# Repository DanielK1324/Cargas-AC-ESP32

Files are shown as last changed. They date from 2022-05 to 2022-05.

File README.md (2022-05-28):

# Cargas-AC-ESP32

Este dispositivo fue diseñado como proyecto final de curso aplicando IOT (Internet de las Cosas)

El dispositivo contiene:

- ESP32
- NeoPixeles
- Buzzer
- SHT30
- Control de cargas AC

# ¿Cómo funciona?

# ¿Qué podemos hacer?

# Descripción de pines 

### Pantalla OLED SSD 1306, Temperatura y Humedad – Comunicación I2C
Referencia --- | SSD 1306 | --- | SHT30 |
ESP32            | SCL IO22 | --- | SCL IO22 |
---------------- | -------- |---- | -------- |
| SSD 1306| --- | SHT30 | 
| SCL IO22 | -- | SCL IO22 |
| SDA IO23 | -- | SDA IO23 |

### Control Cargas AC 
Referencia --- | CARGA 1 | --- | CARGA 2 | --- | CARGA 3 |
ESP32          |  IO25   | --- |  IO26   | --- |  IO27   | 

### LED Neopixel - Comunicación SPI
Referencia --- | WS2812B | 
ESP32            |   SD3   |
5V | VCC 

GND | GND

### Control Cargas AC 
Referencia --- | SCT 013 | --- | Voltaje AC |
ESP32          |  IO15   | --- |     IO2    |
               | ADC2_2  | --- |   ADC2_3   |
# Licencia

Hardware License: CERN OHL v1.0 para más información visitar el siguiente [Link][CERN_v1].

[CERN_v1]: https://ohwr.org/project/cernohl/wikis/Documents/CERN-OHL-version-1.2

Software License: GPL v3

Documentation License: CC BY 4.0 International

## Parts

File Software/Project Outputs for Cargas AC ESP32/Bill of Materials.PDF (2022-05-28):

Comment | Description | Designator | Footprint | LibRef | Quantity
Boton | Micro Push TH | B1, B2 | Push Boton 2P C | Push Boton 2 Pin TH | 2
Buzzer | Active Sound | B3 | Buzzer | Buzzer | 1
100nF | Capacitor cerámico 1206 SMD | C1, C2, C3, C4, C5, C6, C9 | Capacitor 1206 | Capacitor 1206 | 7
10uF | | C7, C8 | 100uF | CAP-ELEC-100uF | 2
1N4004 | Diodo Rectificador | D1, D2, D3 | 1N4007 SMD | 1N4007 SMD | 3
T-Block | Terminal de Bloque 2P 5.08mm | H1, H2, H3, H4 | TBLOCK-2ORANGE | T-Block 5.08mm 2P | 4
ESP32-WRover | ESP32-WRover 39Pins | IC1 | ESP32-WROVER-B | ESP32-WRover | 1
SHT3X | SHT3X | IC2 | DFN-8_DD | SHT3X | 1
PJ-3136 | PJ-3136 Jack De Audio Hembra | J1 | PJ-3136-X | JACK HEMBRA 3.5MM | 1
LED 1206 | LED SMD 1206 | L1 | LED 1206 G | LED 1206 | 1
LED 1206 | LED SMD 1206 | L2 | LED 1206 R | LED 1206 | 1
SSD 1306 | Pantalla OLED 124x64 | L3 | OLEDSSD1306 | SSD 1306 | 1
NEOPIXEL-WS2812B | LED NEOPIXEL WS2812B | L4 | WS2812B | NEOPIXEL-WS2812B | 1
10K | Resistencia SMD 1206 | R1, R2, R3, R4, R5, R6, R9, R10, R16 | Resistencia 1206 | Resistencia SMD 1206 | 9
5.1K | Resistencia SMD 1206 | R7, R8 | Resistencia 1206 | Resistencia SMD 1206 | 2
1K | Resistencia SMD 1206 | R11 | Resistencia 1206 | Resistencia SMD 1206 | 1
100K | Resistencia SMD 1206 | R12 | Resistencia 1206 | Resistencia SMD 1206 | 1
470K | Resistencia SMD 1206 | R13, R14, R19, R20 | Resistencia 1206 | Resistencia SMD 1206 | 4
470 | Resistencia SMD 1206 | R15, R18, R21, R22, R23, R24 | Resistencia 1206 | Resistencia SMD 1206 | 6
22 | Resistencia SMD 1206 | R17 | Resistencia 1206 | Resistencia SMD 1206 | 1
Relevador | Relevador Mini | RL1, RL2, RL3 | Relevador Mini 20A | Relevador S 5V 20A | 3
MMTB2N2222 | | T1, T2 | SOT23_M | MMBT2N2222A | 2
2N3904 | | T3 | NewTO-92A | 2N3904 | 1
2N3904 | | T4, T5, T6 | SOT23_M | MMBT2N3904 | 3
CH340B | USB-Serial Converter | U1 | SOIC 16 | CH340B | 1
AMS1117-3.3V | Regulador Lineal de Voltaje | U2 | SOT 223 | AMS1117 | 1
PC817 | Optoacoplador NPN | U3, U4, U5 | PC817 | PC817 | 3
USB TYPEC C 16PINS | USB Type C 16 Pins | USB-C1 | USB-TYPE_C-16 | USB TYPEC C 16PINS | 1

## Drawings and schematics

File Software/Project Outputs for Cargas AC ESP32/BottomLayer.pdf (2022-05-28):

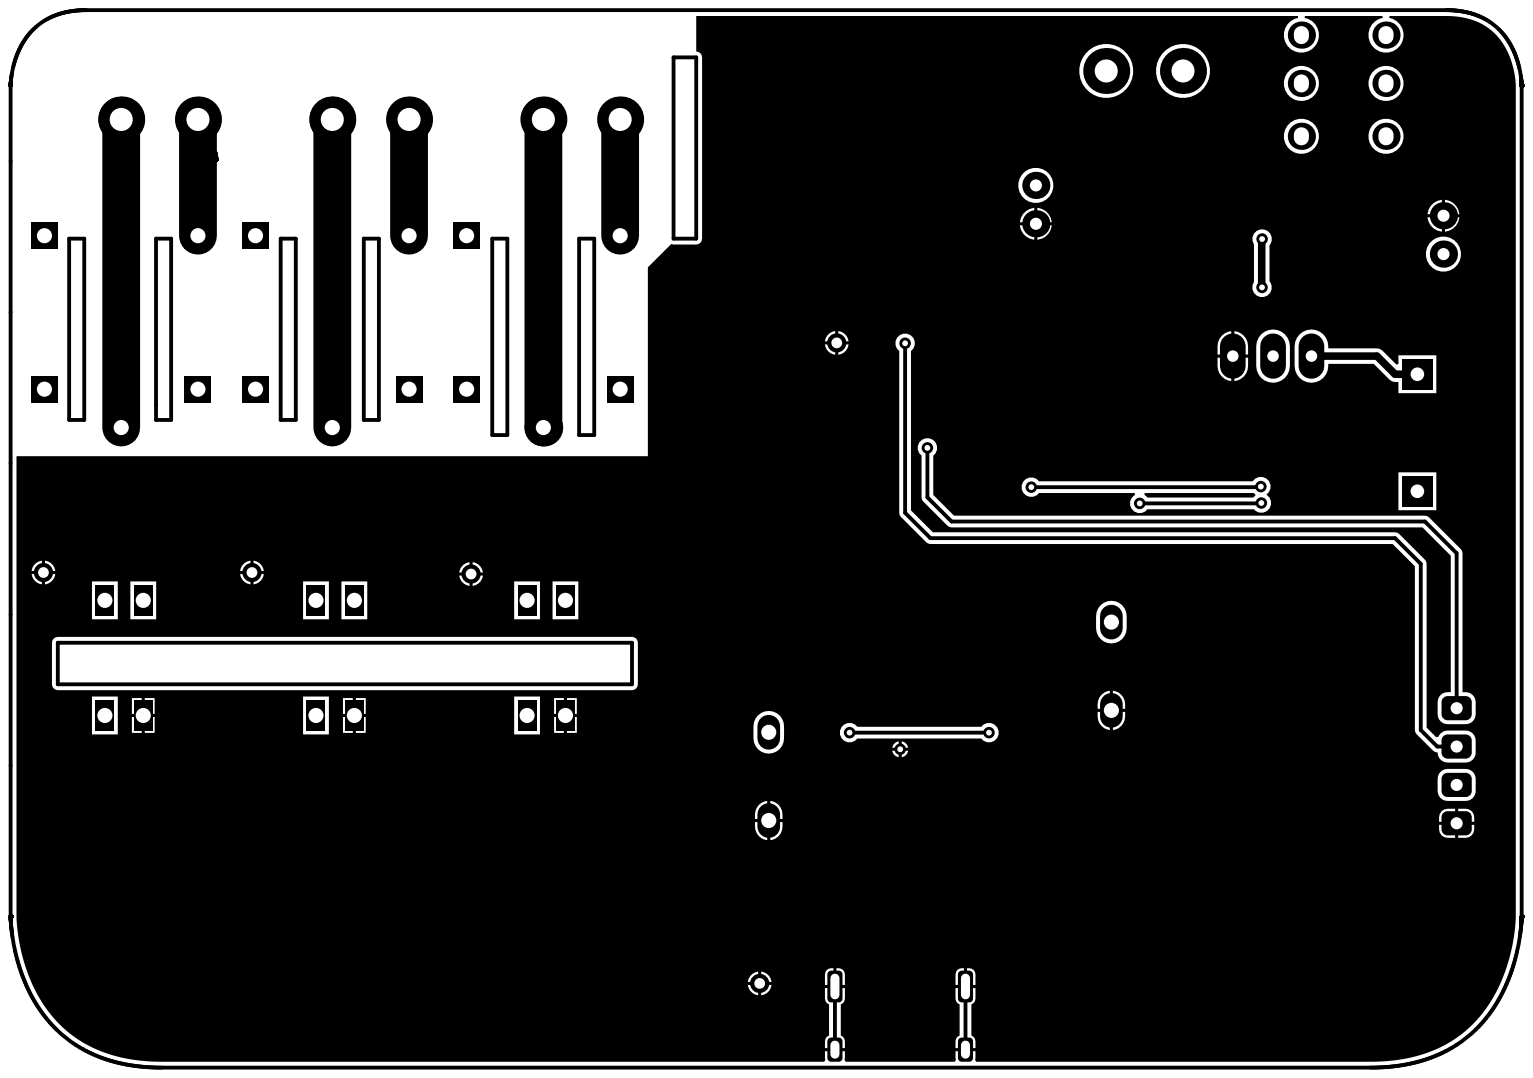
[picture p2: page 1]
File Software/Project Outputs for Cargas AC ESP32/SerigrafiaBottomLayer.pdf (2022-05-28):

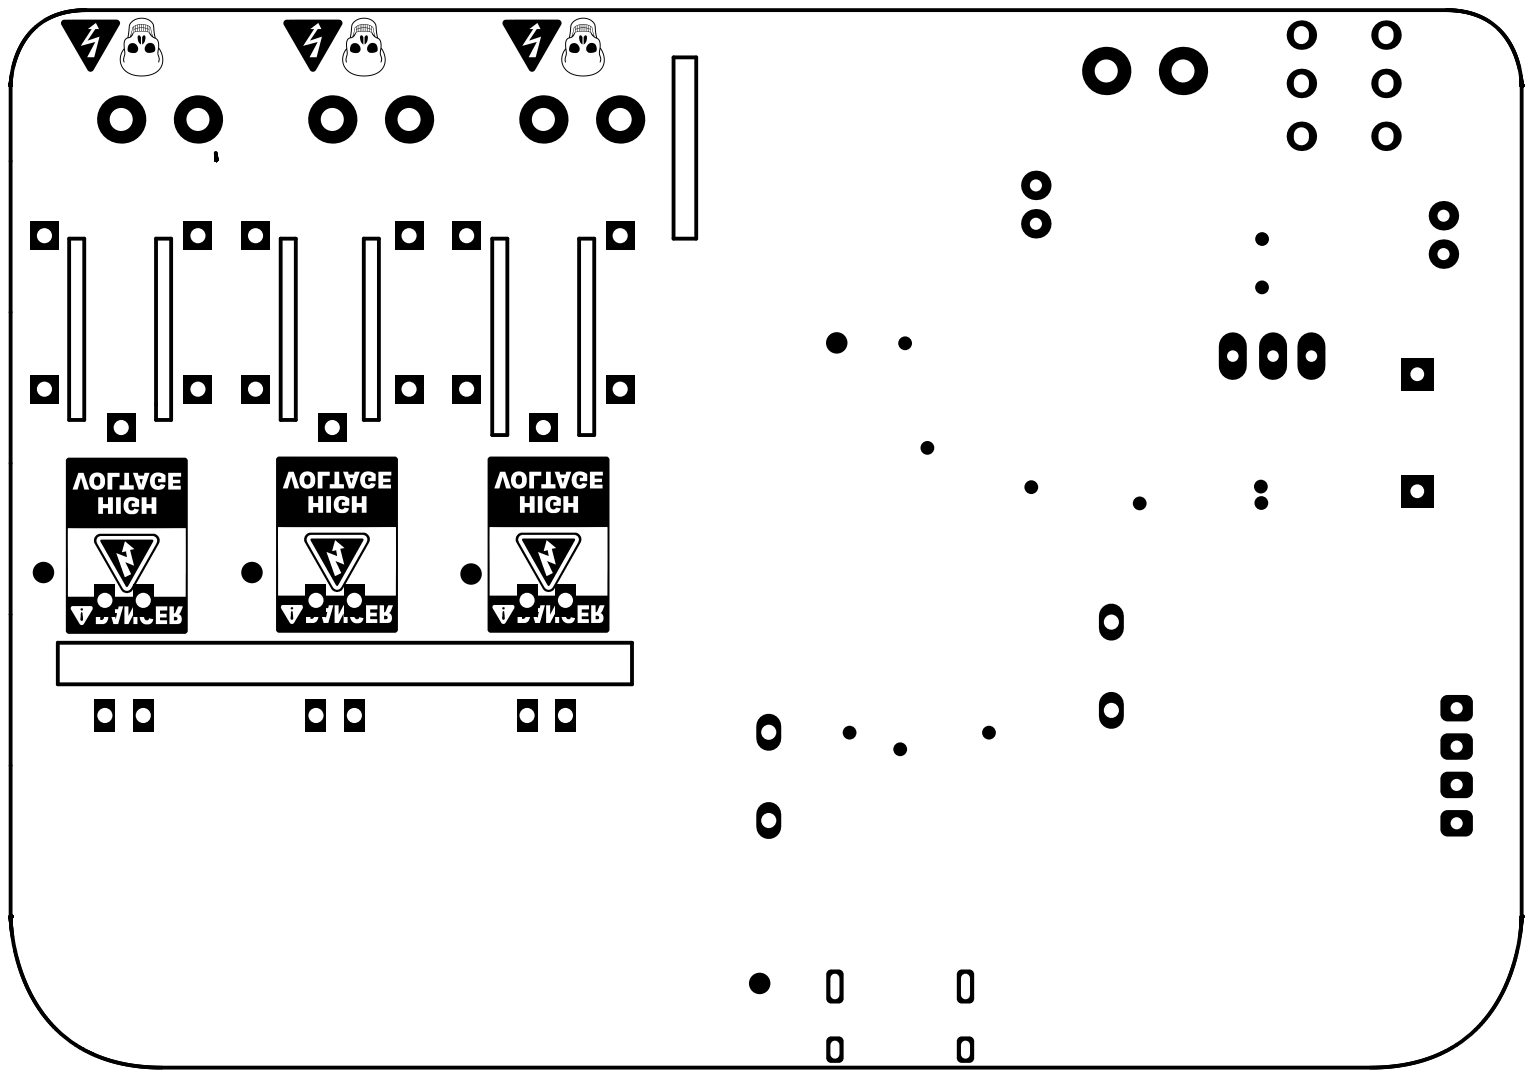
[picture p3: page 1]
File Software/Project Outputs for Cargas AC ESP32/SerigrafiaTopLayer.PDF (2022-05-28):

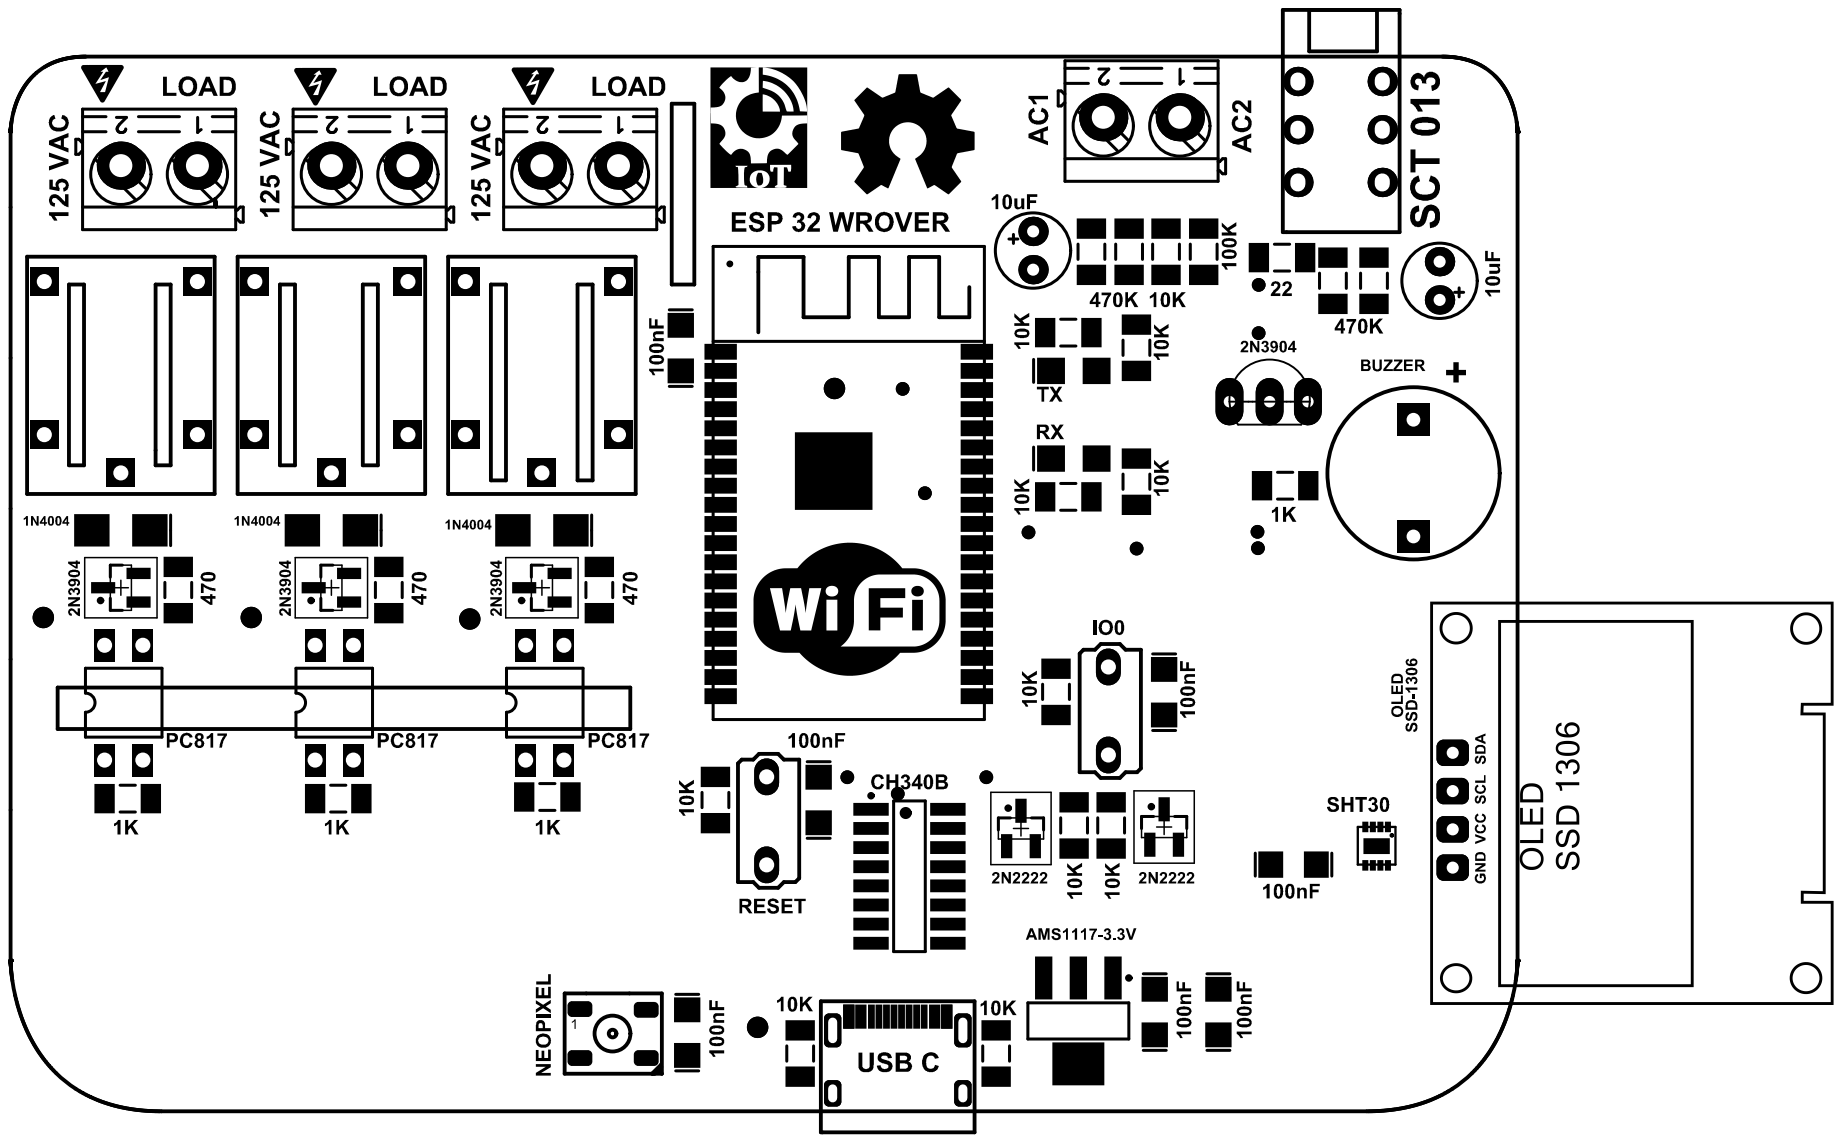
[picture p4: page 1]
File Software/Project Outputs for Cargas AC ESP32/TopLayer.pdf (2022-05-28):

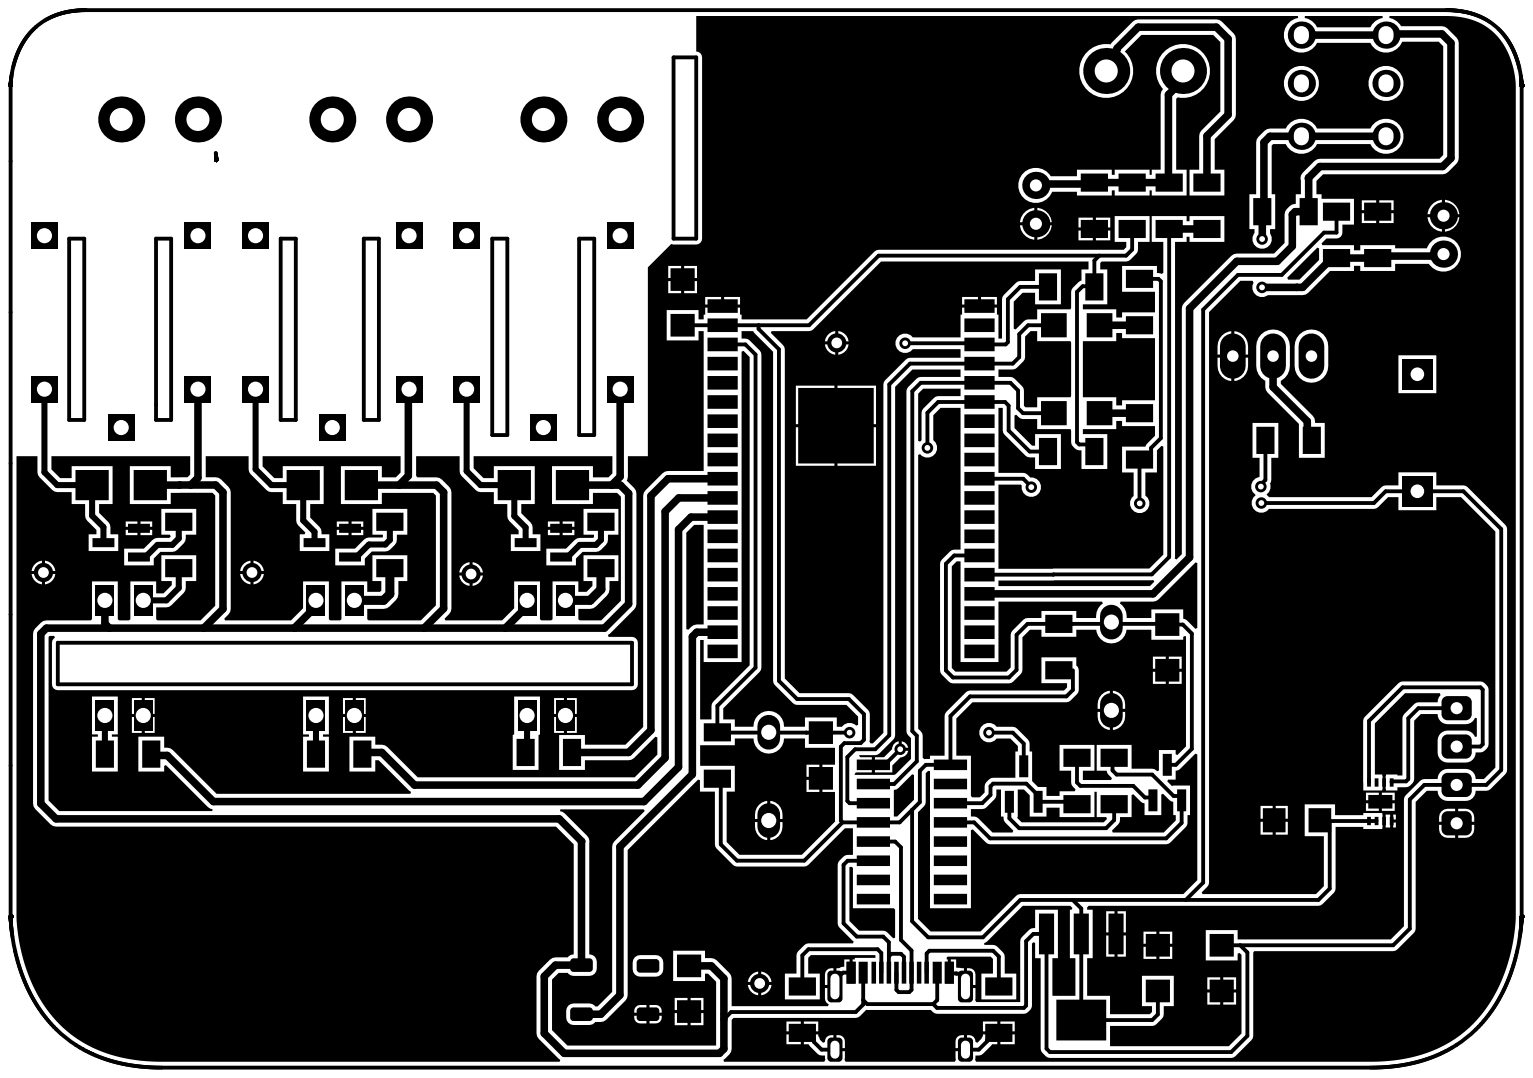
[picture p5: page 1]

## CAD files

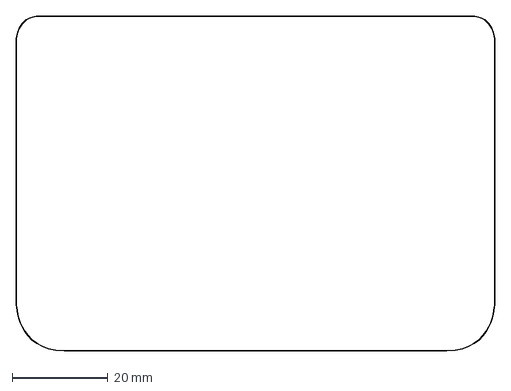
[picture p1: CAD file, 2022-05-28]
Documentacion/PCB.dxf
100.0 x 70.0 mm
